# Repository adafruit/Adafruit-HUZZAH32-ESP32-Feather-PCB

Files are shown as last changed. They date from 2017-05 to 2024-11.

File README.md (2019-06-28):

## Adafruit HUZZAH32 ESP32 Feather

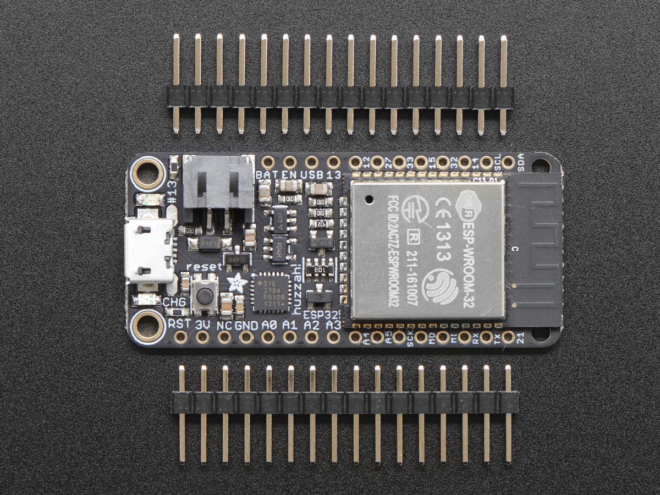
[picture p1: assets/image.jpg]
<a href="http://www.adafruit.com/products/3405"><br/>
Click here to purchase one from the Adafruit shop</a>

PCB files for the Adafruit Feather ESP32 HUZZAH32. Format is EagleCAD schematic and board layout

For more details, check out the product page at
* https://www.adafruit.com/product/3405

### Description

Aww yeah, it's the Feather you have been waiting for! The HUZZAH32 is our ESP32-based Feather, made with the official WROOM32 module. We packed everything you love about Feathers: built in USB-to-Serial converter, automatic bootloader reset, Lithium Ion/Polymer charger, and just about all of the GPIOs brought out so you can use it with any of our Feather Wings. We have other boards in the Feather family, check'em out here.

That module nestled in at the end of this Feather contains a dual-core ESP32 chip, 4 MB of SPI Flash, tuned antenna, and all the passives you need to take advantage of this powerful new processor. The ESP32 has both WiFi and Bluetooth Classic/LE support. That means it's perfect for just about any wireless or Internet-connected project.

Because it's part of our Feather eco-system, you can take advantage of the 50+ Wings that we've designed to add all sorts of cool accessories.

The ESP32 is a perfect upgrade from the ESP8266 that has been so popular. In comparison, the ESP32 has way more GPIO, plenty of analog inputs, two analog outputs, multiple extra peripherals (like a spare UART), two cores so you don't have to yield to the WiFi manager, much higher-speed processor, etc. etc! We think that as the ESP32 gets traction, we'll see more people move to this chip exclusively, as it is so full-featured.

### License

Adafruit invests time and resources providing this open source design, please support Adafruit and open-source hardware by purchasing products from [Adafruit](https://www.adafruit.com)!

Designed by Limor Fried/Ladyada for Adafruit Industries.

Creative Commons Attribution/Share-Alike, all text above must be included in any redistribution. See license.txt for additional details.

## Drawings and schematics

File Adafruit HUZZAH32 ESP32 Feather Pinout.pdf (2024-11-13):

# Adafruit HUZZAH32 ESP32 Feather

# http://www.adafruit.com/products/3405

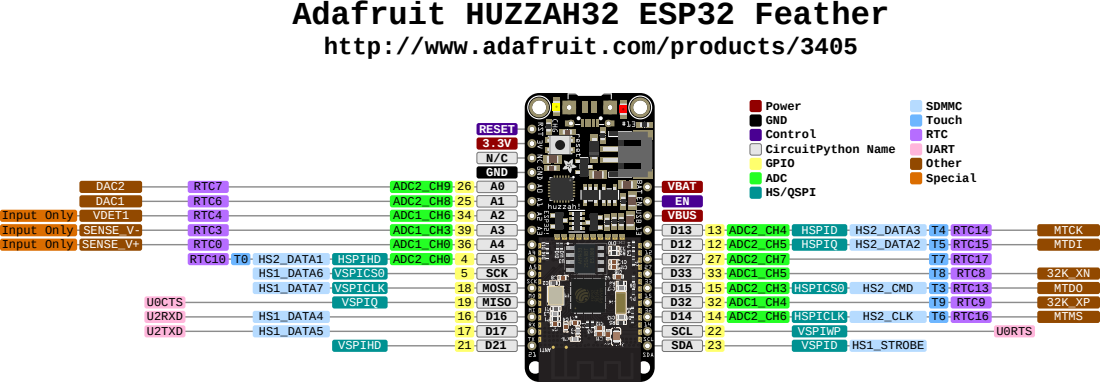
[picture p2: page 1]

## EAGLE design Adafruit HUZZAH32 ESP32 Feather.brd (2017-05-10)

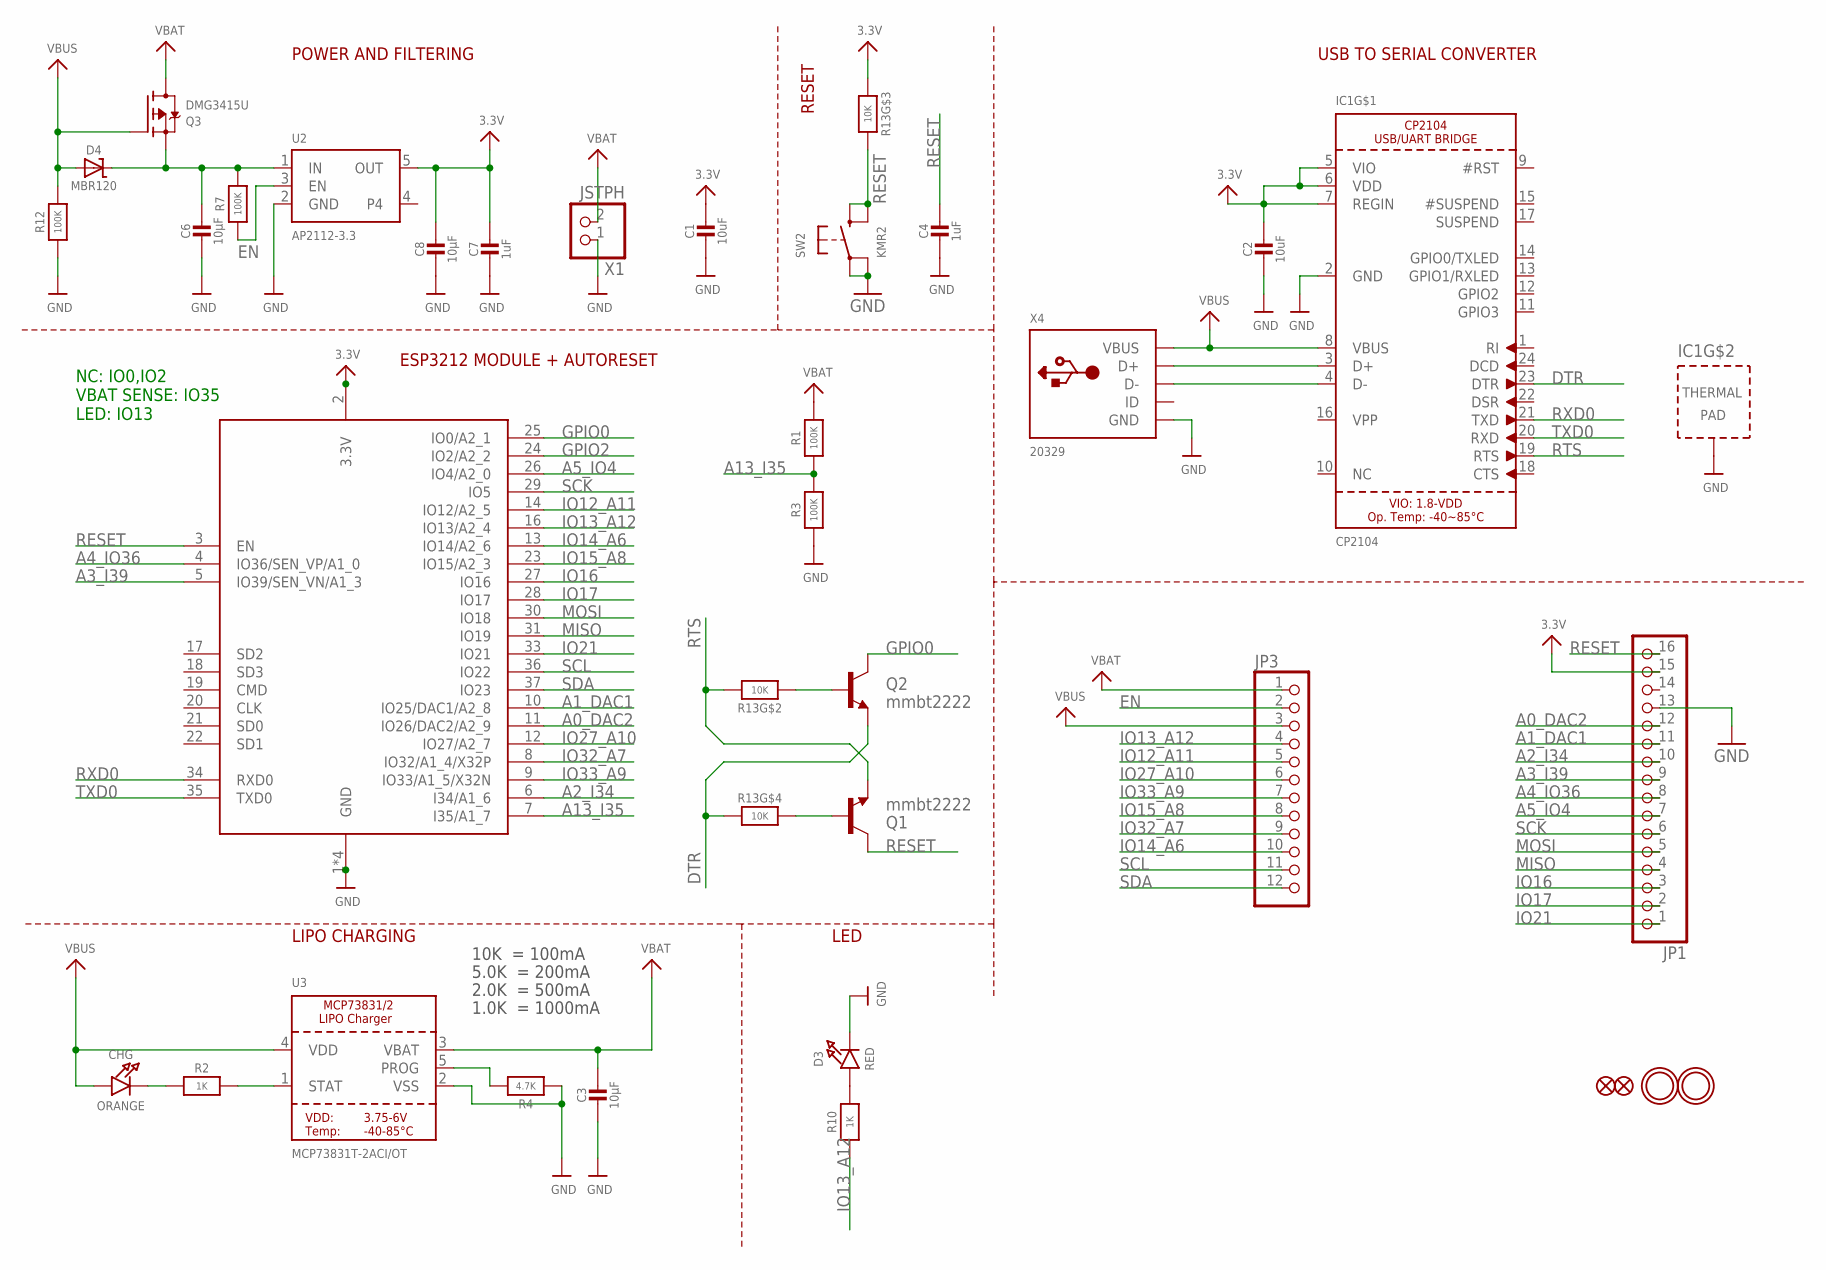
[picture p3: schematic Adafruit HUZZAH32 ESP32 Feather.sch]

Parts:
C1, C2: 10uF; 0805-NO
C3, C6, C8: 10µF; 0805-NO
C4, C7: 1uF; 0603-NO
CHG: ORANGE; CHIPLED_0805_NOOUTLINE
D3: RED; CHIPLED_0805_NOOUTLINE
D4: MBR120; SOD-123
IC1: CP2104; QFN24_4MM_SMSC
JP1: HEADER-1X16_MIN; 1X16_ROUND_MIN
JP3: HEADER-1X12_MIN; 1X12_ROUND_MIN
Q1, Q2: mmbt2222; SOT23-3
Q3: DMG3415U; SOT23-R
R1, R3, R7, R12: 100K; 0603-NO
R2, R10: 1K; 0603-NO
R4: 4.7K; 0603-NO
R13: 10K; RESPACK_4X0603
SW2: KMR2; BTN_KMR2_4.6X2.8
U2: AP2112-3.3; SOT23-5
U3: MCP73831T-2ACI/OT; SOT23-5
U$31, U$32: MOUNTINGHOLE2.5; MOUNTINGHOLE_2.5_PLATED
U$34, U$35: FIDUCIAL_1MM
X1: JSTPH; JSTPH2
X2: ESP32_WROOM32_SKINNY; WROOM32_SKINNY
X4: 20329; 4UCONN_20329_V2

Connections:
3.3V: C1.1, C2.1, C7.1, C8.1, IC1.5 (VIO), IC1.6 (VDD), IC1.7 (REGIN), JP1.15, R13.3 (1), U2.5 (OUT), X2.2 (3.3V)
A0_DAC2: JP1.12, X2.11 (IO26/DAC2/A2_9)
A1_DAC1: JP1.11, X2.10 (IO25/DAC1/A2_8)
A2_I34: JP1.10, X2.6 (I34/A1_6)
A3_I39: JP1.9, X2.5 (IO39/SEN_VN/A1_3)
A4_IO36: JP1.8, X2.4 (IO36/SEN_VP/A1_0)
A5_IO4: JP1.7, X2.26 (IO4/A2_0)
A13_I35: R1.1, R3.2, X2.7 (I35/A1_7)
DTR: IC1.23 (DTR), Q2.2 (E), R13.4 (1)
EN: JP3.2, R7.1, U2.3 (EN)
GND: C1.2, C2.2, C3.2, C4.2, C6.2, C7.2, C8.2, D3.C, IC1.2 (GND), IC1.THERM (TP), JP1.13, R3.1, R4.1, R12.1, SW2.A, SW2.A' (P1), U2.2 (GND), U3.2 (VSS), X1.1, X2.1 (GND), X2.15 (GND), X2.38 (GND), X2.P$1 (GND), X4.BASE@1 (GND), X4.BASE@2 (GND), X4.GND, X4.SPRT@1 (GND), X4.SPRT@2 (GND), X4.SPRT@3 (GND), X4.SPRT@4 (GND)
GPIO0: Q2.3 (C), X2.25 (IO0/A2_1)
GPIO2: X2.24 (IO2/A2_2)
IO12_A11: JP3.5, X2.14 (IO12/A2_5)
IO13_A12: JP3.4, R10.1, X2.16 (IO13/A2_4)
IO14_A6: JP3.10, X2.13 (IO14/A2_6)
IO15_A8: JP3.8, X2.23 (IO15/A2_3)
IO16: JP1.3, X2.27 (IO16)
IO17: JP1.2, X2.28 (IO17)
IO21: JP1.1, X2.33 (IO21)
IO27_A10: JP3.6, X2.12 (IO27/A2_7)
IO32_A7: JP3.9, X2.8 (IO32/A1_4/X32P)
IO33_A9: JP3.7, X2.9 (IO33/A1_5/X32N)
MISO: JP1.4, X2.31 (IO19)
MOSI: JP1.5, X2.30 (IO18)
unnamed: CHG.C, R2.1
unnamed: IC1.3 (D+), X4.D+
unnamed: R2.2, U3.1 (STAT)
unnamed: R4.2, U3.5 (PROG)
unnamed: D3.A, R10.2
unnamed: IC1.4 (D-), X4.D-
unnamed: C6.1, D4.C, Q3.2 (S), R7.2, U2.1 (IN)
unnamed: Q1.1 (B), R13.5 (2)
unnamed: Q2.1 (B), R13.2 (1)
RESET: C4.1, JP1.16, Q1.3 (C), R13.6 (2), SW2.B (S), SW2.B' (S1), X2.3 (EN)
RTS: IC1.19 (RTS), Q1.2 (E), R13.7 (2)
RXD0: IC1.21 (TXD), X2.34 (RXD0)
SCK: JP1.6, X2.29 (IO5)
SCL: JP3.11, X2.36 (IO22)
SDA: JP3.12, X2.37 (IO23)
TXD0: IC1.20 (RXD), X2.35 (TXD0)
VBAT: C3.1, JP3.1, Q3.3 (D), R1.2, U3.3 (VBAT), X1.2
VBUS: CHG.A, D4.A, IC1.8 (VBUS), JP3.3, Q3.1 (G), R12.2, U3.4 (VDD), X4.VBUS

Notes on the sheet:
POWER AND FILTERING
RESET
10K = 100mA
5.0K = 200mA
2.0K = 500mA
1.0K = 1000mA
USB TO SERIAL CONVERTER
LIPO CHARGING
LED
ESP3212 MODULE + AUTORESET
NC: IO0,IO2 VBAT SENSE: IO35 LED: IO13

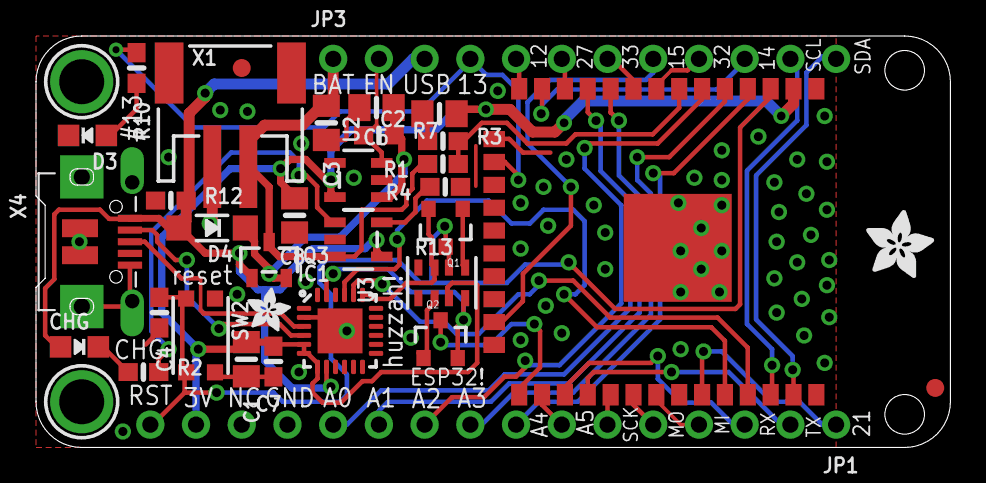
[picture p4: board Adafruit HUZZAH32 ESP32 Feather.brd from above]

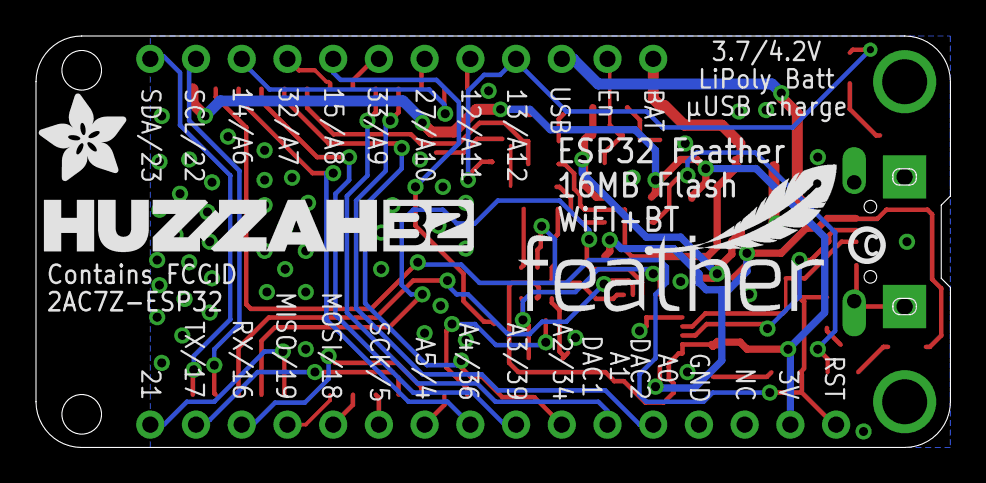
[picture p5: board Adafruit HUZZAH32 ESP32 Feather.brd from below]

Board: 2 copper layers, 50.8 x 22.9 mm, 40 parts (4 on the bottom side), 42 nets.

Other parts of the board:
U$7: ADAFRUIT_5MM
U$9: FEATHERLOGO_MED
U$13: PCBFEAT-REV-040
U$14: ADAFRUIT_2.5MM
U$15: ADAFRUIT_3.5MM
U$43: HUZZAH32

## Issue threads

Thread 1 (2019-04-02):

BOM list for this pcb board

kenken64, 2019-04-02:
Hi Adafruit,

Can I have the bom list of the compoents?

ladyada, 2019-04-02:
you can extract it from eagle using their tools

laikhooi, 2023-06-26:
Can share the BOM list for Adafruit ESP32 Feather V2

Closed 2019-04-02.

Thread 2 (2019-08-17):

I2C - SPI pins

nerdyscout, 2019-08-17:
I had a deeper look into some of the pin assignments and can't get rid of the feeling there is something wrong on your schematic... or maybe you could help me to understand it better.

|[ESP32](https://www.espressif.com/sites/default/files/documentation/esp32_datasheet_en.pdf)|Function|comment|
|-|-|-|
|GPIO23|GPIO23,VSPID=MOSI|but SDA seems connected |
|GPIO05|GPIO05,VSPICS|but CLK is connected, why not VSPICLK=GPIO18?|

thx

ladyada, 2019-08-17:
we use the pins that are easiest to access, you can have I2C/SPI on any pins you like

Closed 2019-08-17.

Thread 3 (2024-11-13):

Problem with board pin assignments on Huzzah32 ESP32 Feather

sbonaime, 2024-11-13:
### CircuitPython version

```python
Adafruit CircuitPython 9.2.0 on 2024-10-28; Adafruit Feather HUZZAH32 with ESP32
```

### Code/REPL

```python
>>> import board
>>> dir(board)
['__class__', '__name__', 'A0', 'A1', 'A10', 'A11', 'A12', 'A2', 'A3', 'A4', 'A5', 'A6', 'A7', 'A8', 'A9', 'D12', 'D13', 'D14', 'D15', 'D16', 'D17', 'D18', 'D19', 'D21', 'D22', 'D23', 'D25', 'D26', 'D27', 'D32', 'D33', 'D34', 'D35', 'D36', 'D39', 'D4', 'D5', 'I2C', 'LED', 'MISO', 'MOSI', 'NEOPIXEL', 'RX', 'SCK', 'SCL', 'SDA', 'SPI', 'TX', 'UART', 'VOLTAGE_MONITOR', '__dict__', 'board_id']
```

### Behavior

['__class__', '__name__', 'A0', 'A1', 'A10', 'A11', 'A12', 'A2', 'A3', 'A4', 'A5', 'A6', 'A7', 'A8', 'A9', 'D12', 'D13', 'D14', 'D15', 'D16', 'D17', 'D18', 'D19', 'D21', 'D22', 'D23', 'D25', 'D26', 'D27', 'D32', 'D33', 'D34', 'D35', 'D36', 'D39', 'D4', 'D5', 'I2C', 'LED', 'MISO', 'MOSI', 'NEOPIXEL', 'RX', 'SCK', 'SCL', 'SDA', 'SPI', 'TX', 'UART', 'VOLTAGE_MONITOR', '__dict__', 'board_id']

### Description

I am trying to use an Adafruit Feather HUZZAH32 with ESP32. But according to this adafruit document
https://learn.adafruit.com/adafruit-huzzah32-esp32-feather/pinouts
I should find board.IO12
But no IO pins are available.

### Additional information

_No response_

dhalbert, 2024-11-13:
@sbonaime I fixed the pin-out diagram to use "D" instead of "IO".

Closed 2024-11-13.

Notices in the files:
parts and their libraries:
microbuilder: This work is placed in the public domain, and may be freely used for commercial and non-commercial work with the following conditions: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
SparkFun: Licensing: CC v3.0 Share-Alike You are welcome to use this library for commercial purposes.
